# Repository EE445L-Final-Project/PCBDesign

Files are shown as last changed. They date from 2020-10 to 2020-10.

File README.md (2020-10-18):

# EE445L Final Project PCB Repository
This repository contains the schematics and board of the final design. For code part, please visit other repo.
## Note
This file format can only be opened by __Autodesk Eagle__.
## Download this Repository
```git clone https://github.com/EE445L-Final-Project/PCBDesign.git```

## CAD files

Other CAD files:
Box/2-SMD-5X3, NX5032GA_37.ipt
Box/Assembly1.iam
Box/B3F-10XX, RST_B3F-10XX_60.ipt
Box/B3F-10XX, SW-PC4_B3F-10XX_62.ipt
Box/B3F-10XX, SW-PF0_B3F-10XX_64.ipt
Box/BGM220P, BGM220P_6.ipt
Box/BLE Board.brd.iam
Box/BLE Board.brd_Outline.ipt
Box/Box Top.ipt
Box/Box.ipt
Box/C0603K, 0_01UF_17.ipt
Box/C0603K, 0_1UF_10.ipt
Box/C0603K, 10PF_24.ipt
Box/C0603K, 10UF_27.ipt
Box/C0603K, 1UF_13.ipt
Box/C0603K, 2_2UF_15.ipt
Box/C0603K, 4_7UF_33.ipt
Box/DRC-S-PVSON-N10, TPS6300_46.ipt
Box/IND_LPS3015, I1_IND_LPS3015_42.ipt
Box/JSTPH2, JST_3.ipt
Box/JTAG_SERIAL_PTH, JTAG_SERIAL_48.ipt
Box/OldVersions/Assembly1.0003.iam
Box/OldVersions/Box Top.0004.ipt
Box/OldVersions/Box.0005.ipt
Box/P1_1MM, TP_KEYSTONE500X_1.ipt
Box/R0603, 100_56.ipt
Box/R0603, 10K_52.ipt
Box/R0603, 1M_54.ipt
Box/SAMTEC-FTSH-105-01-X-DV, SAMTEC-FTSH-105-01-X-DVJ_8.ipt
Box/SQFP-S-10X10-64, TM4C123GH6PM_44.ipt
Box/ST7735, ST7735_39.ipt
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

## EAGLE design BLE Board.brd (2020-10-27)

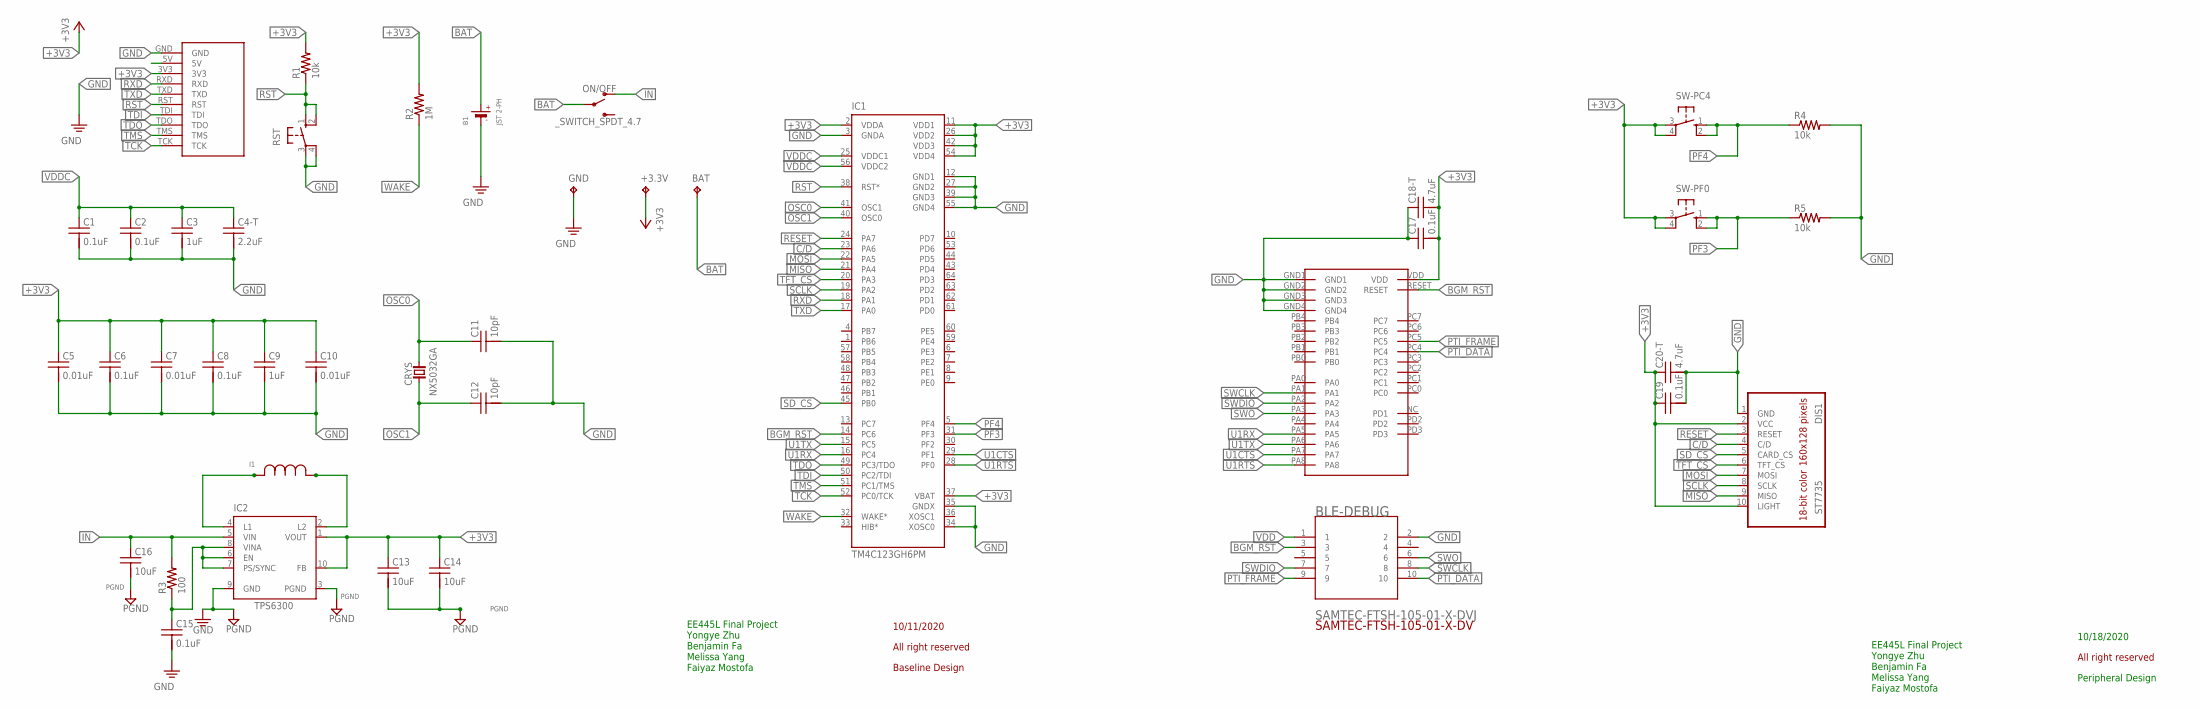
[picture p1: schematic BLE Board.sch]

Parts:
+3.3V: TP_KEYSTONE500X; P1.1MM
B1: JST 2-PH; JSTPH2
BAT: TP_KEYSTONE500X; P1.1MM
BLE: BGM220P
BLE-DEBUG: SAMTEC-FTSH-105-01-X-DVJ; SAMTEC-FTSH-105-01-X-DV
C1, C2, C6, C8, C15, C17, C19: 0.1uF; C0603K
C3, C9: 1uF; C0603K
C4-T: 2.2uF; C0603K
C5, C7, C10: 0.01uF; C0603K
C11, C12: 10pF; C0603K
C13, C14, C16: 10uF; C0603K
C18-T, C20-T: 4.7uF; C0603K
CRYS: NX5032GA; 2-SMD-5X3
DIS1: ST7735
GND: TP_KEYSTONE500X; P1.1MM
I1: IND_TPS; IND_LPS3015
IC1: TM4C123GH6PM; SQFP-S-10X10-64
IC2: TPS6300; DRC-S-PVSON-N10
JTAG: JTAG_SERIAL; JTAG_SERIAL_PTH
ON/OFF: _SWITCH_SPDT_4.7
R1, R4, R5: 10k; R0603
R2: 1M; R0603
R3: 100; R0603
RST: B3F-1052; B3F-10XX
SW-PC4: B3F-1052; B3F-10XX
SW-PF0: B3F-1052; B3F-10XX

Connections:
+3V3: +3.3V.TP, BLE.VDD, C5.1, C6.1, C7.1, C8.1, C9.1, C10.1, C13.1, C14.1, C17.2, C18-T.2, C19.1, C20-T.1, DIS1.2 (VCC), DIS1.10 (LIGHT), IC1.2 (VDDA), IC1.11 (VDD1), IC1.26 (VDD2), IC1.37 (VBAT), IC1.42 (VDD3), IC1.54 (VDD4), IC2.1 (VOUT), IC2.10 (FB), JTAG.3V3, R1.2, R2.2, SW-PC4.3, SW-PC4.4 (P1), SW-PF0.3, SW-PF0.4 (P1)
BAT: B1.2 (+), BAT.TP, ON/OFF.P$2
BGM_RST: BLE.RESET, BLE-DEBUG.3, IC1.14 (PC6)
C/D: DIS1.4 (C/D), IC1.23 (PA6)
GND: B1.1 (-), BLE.GND1, BLE.GND2, BLE.GND3, BLE.GND4, BLE-DEBUG.2, C1.2, C2.2, C3.2, C4-T.2, C5.2, C6.2, C7.2, C8.2, C9.2, C10.2, C11.2, C12.2, C15.2, C17.1, C18-T.1, C19.2, C20-T.2, DIS1.1 (GND), GND.TP, IC1.3 (GNDA), IC1.12 (GND1), IC1.27 (GND2), IC1.34 (XOSC0), IC1.35 (GNDX), IC1.39 (GND3), IC1.55 (GND4), IC2.9 (GND), JTAG.GND, R4.2, R5.2, RST.3, RST.4 (P1)
IN: C16.1, IC2.5 (VIN), ON/OFF.P$1 (O), R3.2
MISO: DIS1.9 (MISO), IC1.21 (PA4)
MOSI: DIS1.7 (MOSI), IC1.22 (PA5)
unnamed: C15.1, IC2.6 (EN), IC2.7 (PS/SYNC), IC2.8 (VINA), R3.1
unnamed: I1.2, IC2.4 (L1)
unnamed: I1.1, IC2.2 (L2)
OSC0: C11.1, CRYS.2, IC1.41 (OSC1)
OSC1: C12.1, CRYS.1, IC1.40 (OSC0)
PF3: IC1.31 (PF3), R5.1, SW-PF0.1 (S), SW-PF0.2 (S1)
PF4: IC1.5 (PF4), R4.1, SW-PC4.1 (S), SW-PC4.2 (S1)
PGND: C13.2, C14.2, C16.2, IC2.3 (PGND)
PTI_DATA: BLE.PC4, BLE-DEBUG.10
PTI_FRAME: BLE.PC5, BLE-DEBUG.9
RESET: DIS1.3 (RESET), IC1.24 (PA7)
RST: IC1.38 (RST*), JTAG.RST, R1.1, RST.1 (S), RST.2 (S1)
RXD: IC1.18 (PA1), JTAG.RXD
SCLK: DIS1.8 (SCLK), IC1.19 (PA2)
SD_CS: DIS1.5 (CARD_CS), IC1.45 (PB0)
SWCLK: BLE.PA1, BLE-DEBUG.8
SWDIO: BLE.PA2, BLE-DEBUG.7
SWO: BLE.PA3, BLE-DEBUG.6
TCK: IC1.52 (PC0/TCK), JTAG.TCK
TDI: IC1.50 (PC2/TDI), JTAG.TDI
TDO: IC1.49 (PC3/TDO), JTAG.TDO
TFT_CS: DIS1.6 (TFT_CS), IC1.20 (PA3)
TMS: IC1.51 (PC1/TMS), JTAG.TMS
TXD: IC1.17 (PA0), JTAG.TXD
U1CTS: BLE.PA7, IC1.29 (PF1)
U1RTS: BLE.PA8, IC1.28 (PF0)
U1RX: BLE.PA5, IC1.16 (PC4)
U1TX: BLE.PA6, IC1.15 (PC5)
VDD: BLE-DEBUG.1
VDDC: C1.1, C2.1, C3.1, C4-T.1, IC1.25 (VDDC1), IC1.56 (VDDC2)
WAKE: IC1.32 (WAKE*), R2.1

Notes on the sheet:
10/11/2020
All right reserved
Baseline Design
EE445L Final Project Yongye Zhu Benjamin Fa Melissa Yang Faiyaz Mostofa
Peripheral Design
10/18/2020

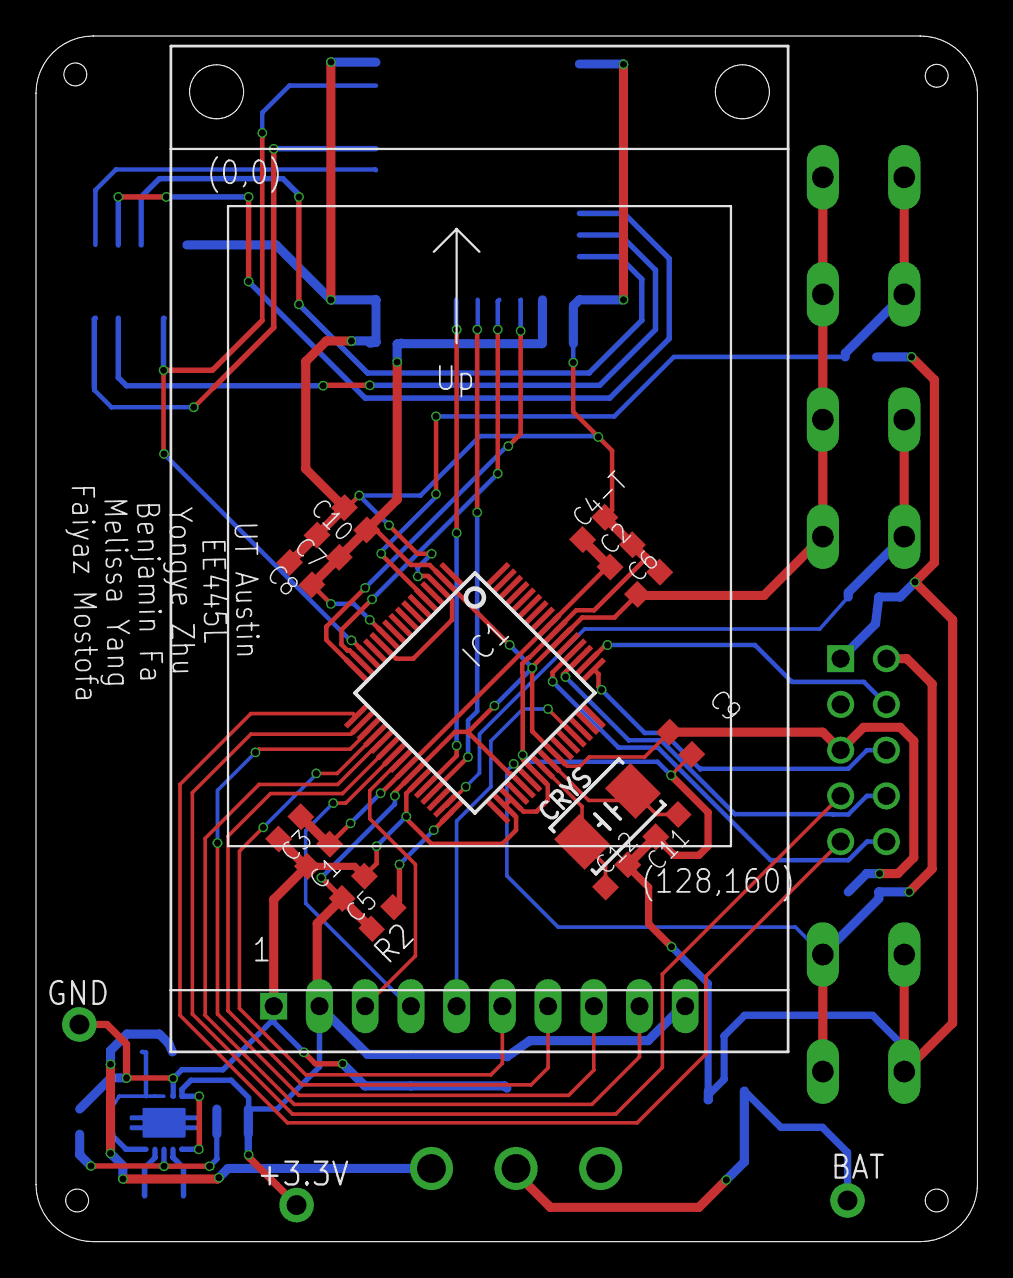
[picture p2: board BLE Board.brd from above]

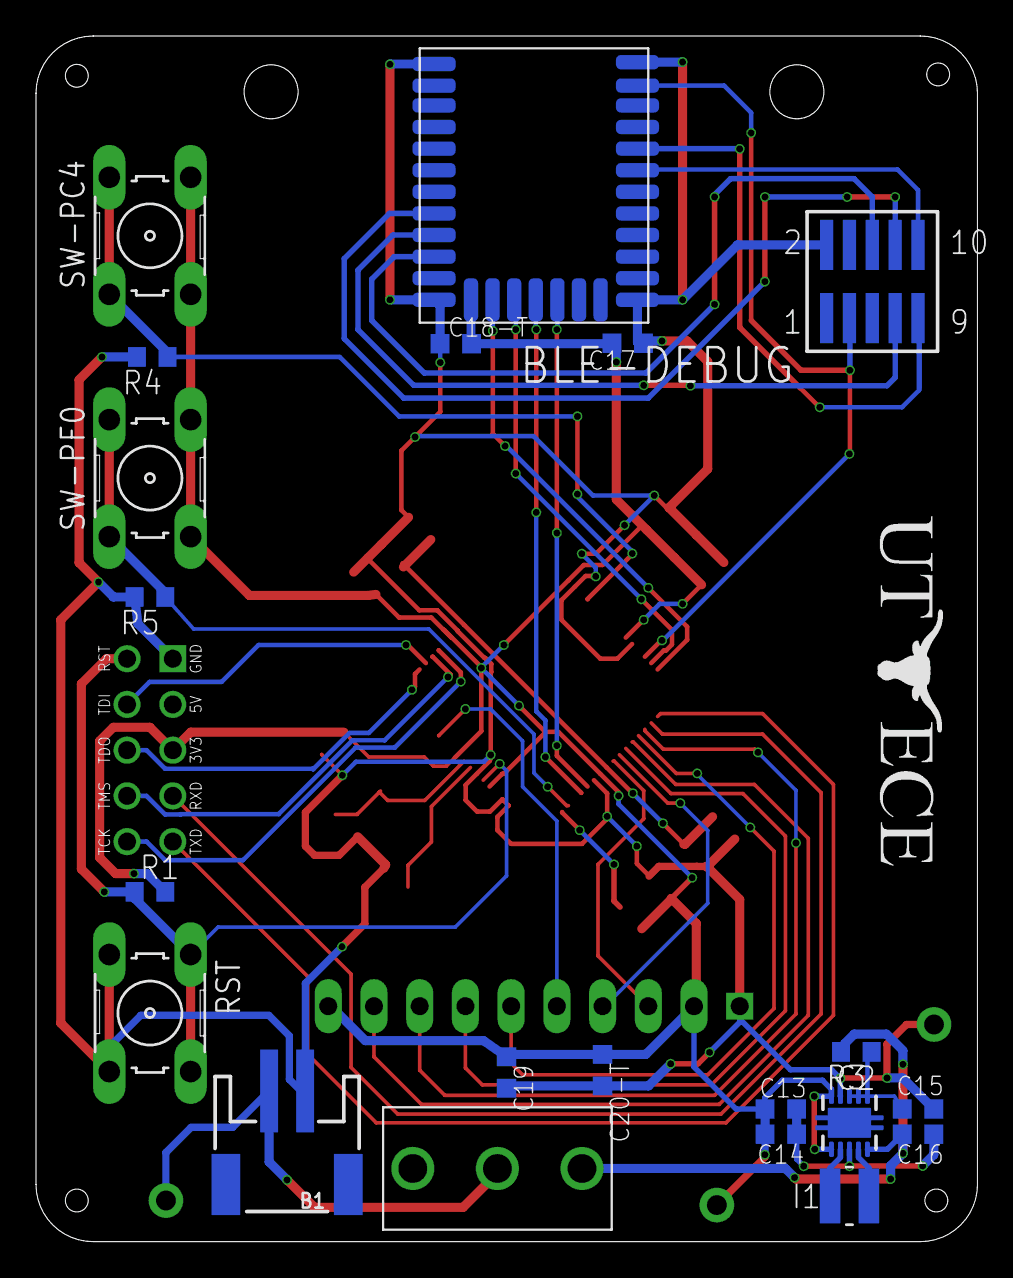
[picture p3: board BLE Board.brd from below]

Board: 2 copper layers, 52.3 x 67.0 mm, 42 parts (23 on the bottom side), 38 nets.

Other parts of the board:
U$1: __LOGO_UT_ECE

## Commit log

2020-10-18 First commit, add sch and brd file
    [BLE Board.brd, BLE Board.sch]
2020-10-19 First arrangement of components
    [BLE Board.brd, BLE Board.sch]
2020-10-19 revised BLE layout
    [BLE Board.brd]
2020-10-19 Flip the LCD
    [BLE Board.brd]
2020-10-19 Fix all errors
    [BLE Board.brd]
2020-10-20 First traces
    [BLE Board.brd]
2020-10-20 Add label
    [BLE Board.brd]
2020-10-22 Moved power reg., changed some parts
    [BLE Board.brd, BLE Board.sch]
2020-10-22 Change button name on board
    [BLE Board.brd]
2020-10-22 0603 cap/res, add test pts for gnd/pwr
    [BLE Board.brd, BLE Board.sch]
2020-10-26 Change direction of battery connector
    [BLE Board.brd]
2020-10-27 Fix wire issue
    [BLE Board.brd]
2020-10-27 Final Commit
    [BLE Board.brd]
2020-11-03 Added the Bottom Box files
    Working on the Top box right now
    [2-SMD-5X3, NX5032GA_37.ipt, Assembly1.iam, B3F-10XX, RST_B3F-10XX_60.ipt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]
2020-11-03 Added the Box files
    [Assembly1.0003.iam, Assembly1.iam, Box Top.0003.ipt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]
2020-11-03 Added LCD window to top
    [Box Top.0003.ipt, Box Top.0004.ipt, Box Top.ipt]

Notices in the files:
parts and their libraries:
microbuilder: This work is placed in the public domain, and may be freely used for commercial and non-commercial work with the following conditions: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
